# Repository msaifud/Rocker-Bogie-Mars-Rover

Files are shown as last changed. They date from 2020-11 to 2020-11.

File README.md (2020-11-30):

# Rocker-Bogie-Mars-Rover
This project was to construct an autonomous robot to be able to scale the surface of Mars.
Given Mars has an unpredictable and uneven surface the robot would have to maintaining a level body throughout motion in order to keep valuable components within the robot safe. 
Keeping a level body is essential and was done using a differential gear system.
The robot used an Arduino to implement the autonomous behaviour. 
I have attached all the 3D modeled parts, the final assembly as well as renders of the final product (placed into the reports). Moreover, a tenchincal report is also attached explaining the process and solution method. 
Additionally, the landscape was also 3D modeled to replicate an uneven and unpredictable path for the robot. That is also attached.

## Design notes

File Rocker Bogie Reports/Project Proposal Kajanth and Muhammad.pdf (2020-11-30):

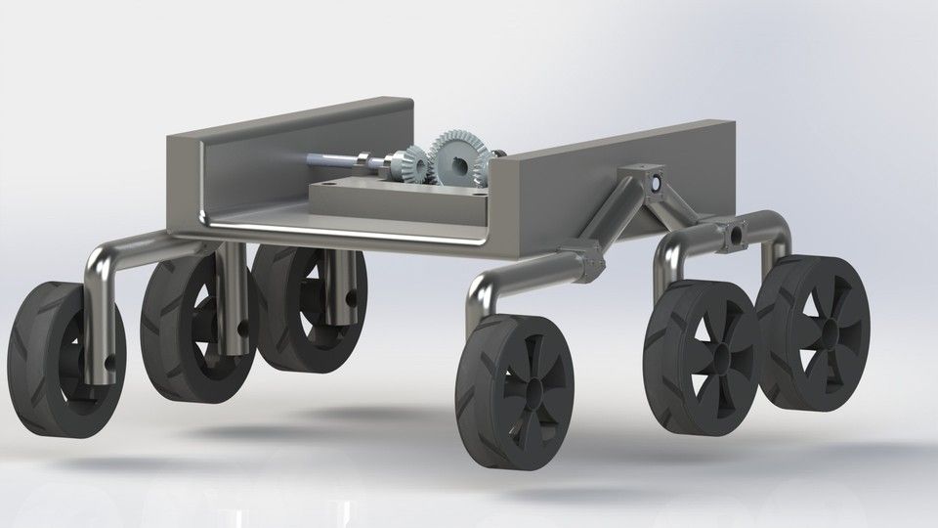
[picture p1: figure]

# Bogie Rocker System Project

09.12.2017
─

## Kajanth Kirupananthan & Muhammad Saifuddin

## Executive Summary

The goal of the following project is to implement the rocker-bogie system into an autonomous robot; which will have the function of keeping a level surface; that will be able to carry a cup from one end of a harsh simulated rocky surface to the other. The following project will involve designing, programming and building an autonomous robot that will be inspired by the bogie-rocker system implemented on the mars rover, said bogie rocker system will be tasked with maintaining a level body even through harsh rocky environments.

## Table of Contents

The Problem and The Fix | 1
Execution Plan | 2
Budgeting | 3
Team Qualifications | 4

## The Problem

Many Space organizations such as Nasa, create explorer devices to go explore the unknowns of our universe and send information back to earth. These devices cost billions to build and produce; these major investments would go to nothing if the explorer robot sustained damaged by the harsh surfaces of the unknown worlds because all the money and time spent on the robot would be lost. To summarize many explorer robots sent to other planets need a system to keep a level surface to protect said robot from sustaining any damage over the course of the exploration mission.

## The Fix

To ensure that all valuable information gets back to earth these robots attempt to implement the rocker-bogie system. The rocker-bogie system uses a series of gears and movable wheels to ensure a level surface that would protect all components from the harsh terrain at all times. Thus, preventing critical blows to the valuable technology and information that is housed in the robot. The following project will attempt to implement the bogie rocker system on a small scale robot as a proof of concept. Said robot will be tasked with proceeding through a simulated rocky path while keeping a level surface at all times to prove the concept of the rocker-bogie system.

## The Execution Plan

### Phase 1: Design Phase (due at the end of September 2017)

- Components that are crucial to the robot must be decided beforehand to ensure the design will account for proper housing or said components.
- Drawings of the exterior body must be drafted to ensure a body that will be able to house both the components of the rocker-bogie system as well as the glass of water itself.
- An inventor cad must be designed to be able to print the frame in such a way that all components may interlock thus, making the assembly of the robot easy. The framework must be designed to be sturdy while also accounting for hidden sections for the wiring to work through.
- Assembly of Robot must show a movable, working wheel and gear system, to ensure that after being built the robot will maintain a level surface.

### Phase 2: Prototyping Phase (1 month)

- The prototype must be made through scraps in the shop at that time to verify a working rocker-bogie system.
- If said prototype does not show the system working successfully, iterations must be made to the cad and the prototype.
- Iterations must be done until Mr.Rattray and both group members are confident with the design of the robot.
- After the design is completed all materials needed must be finalized and ordered.

### Phase 3: Building Phase (until December 2017)

- Building will commence when all materials have arrived
- Parts must be 3d printed beforehand to ensure enough time to build the robot
- All wiring and components must be secured and wiring must be hidden to ensure all components take no damage
- All joints must rotate smoothly

### Phase 4: Programming (second week January)

- Using an Arduino (model to be decided) and all other electrical components on the robot, it must be coded to execute and safely move through a path and keep a stable body to carry a glass of water
- Timings must be made and iterated upon to ensure the robot moves through path correctly
- Code must run perfectly back and forth before the final stage of

### Phase 5: Testing

- The end product must successfully make it through path consistently.
- The end product must also prove its rocker-bogie system is working by keeping a cup of water full even after making it through the path.

## Budgeting

Product | Price | Quantity | Website
Vex motor | $19.99 | 4 | Robotshop
Vex cortex | $324.99 | 1 | Robotshop
Vex battery | $12.99 | 2 | Robotshop
Vex Wiring
3D print material (PLA Filament) | $19.99 | 2 | Robotshop
bearings | To be decided
Differential gear system | To be 3D printed | 1 | N/A
Metals rods | $19.98 | To be decided (diameter of rod is under determination) | Home Depot
Block of wood for cnc | $33.20 | To be decided | Home depot
LED strips | $21.99 | 1 roll | Amazon.ca
High traction vex | $6.99/each | 6 | Vex Robotics

## Team Qualifications: the “Who?”

- Kajanth
- Coding
- Building
- Cading/ CNC
- Designing
- Muhammad
- Cading/CNC
- Building
- Presentation design
- Path design

## Path Followed by Designed Robot

- Description
- The path is designed in this manner for two reasons
■ Because conditions on said planet are extremely unpredictable (one part of the rover can be on a different level than the other)
■ To demonstrate the capabilities of the rover

wheels
Estimated Cost | $550

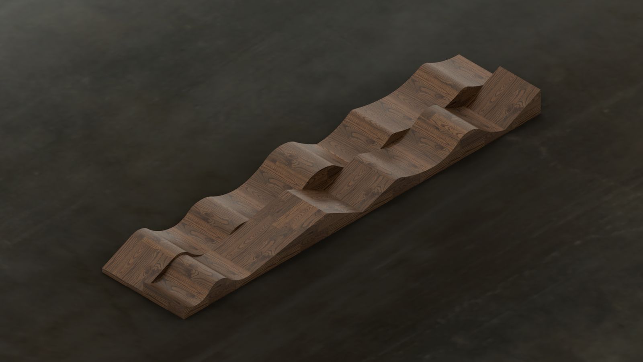
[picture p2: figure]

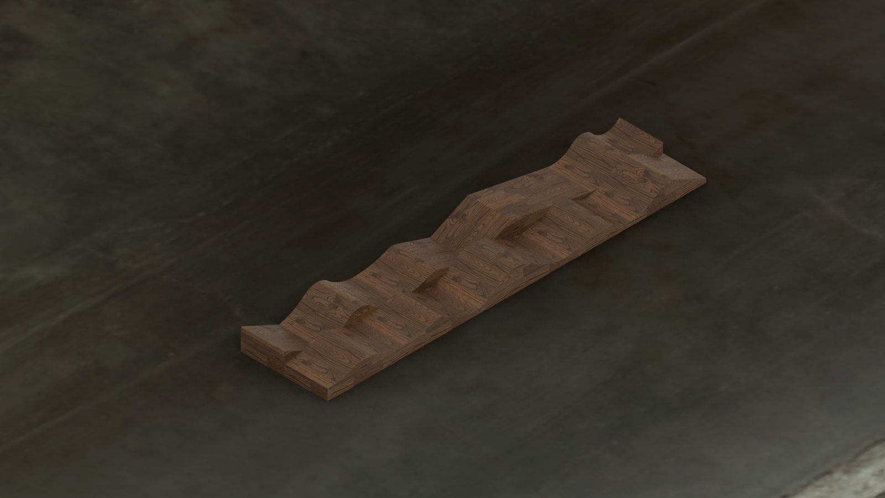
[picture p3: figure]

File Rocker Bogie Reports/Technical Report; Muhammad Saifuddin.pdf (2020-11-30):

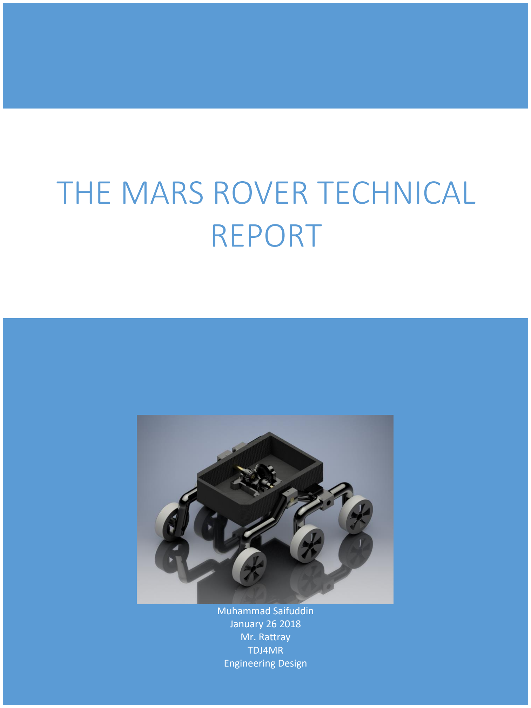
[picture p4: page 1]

Muhammad Saifuddin
January 26 2018
Mr. Rattray
TDJ4MR
Engineering Design

# THE MARS ROVER TECHNICAL REPORT

### The Challenge:

The objective of the Mars Rover assignment was to build a robotic vehicle that would have the capabilities of successfully maneuvering itself through rugged and rigorous surfaces; in addition to this the robot would also have to maintain a level body throughout the course of its movement. Moreover, the robotic vehicle was also given the challenge of recording the gasses in its environment while it was under exploration, this enhanced the simulation of a real mission.

### Rationale:

The proposed challenge has extensive and extremely useful applications. As, in various situations in the real-world, where because of certain circumstances only robotic vehicles can be used oppose to human for exploration; the robot would have to navigate its way through unexpected/harsh terrain while also maintaining a level body. The reason for maintaining a level body is significant to the capabilities of the robot, because at times where the robot is carrying several billion dollar components, if any damage is to be gained then this can compromise the mission in its entirety and defeating the purpose for exploration. Therefore, the robot designed in this specific manner, can be applied to future robots; this ensuring that a misfortunate event of broken components does not occur. Furthermore, the addition of the gas sensors of the robot enhances its capabilities and adds to its effectiveness in the real-world; the data acquired from the robot can be dramatically affect the human race, by detecting gasses that pass as habitable or not, this then allowing humans to create plans for the future, when larger planets are required for the growth of the human race.

### The Brainstorming Stage:

So to complete the challenge at hand, my partner and I first conducted research on past built robots that were specifically designed in a similar manner to the challenge given to us. While conducting research, we came across the Mars Rover; we
then conducted researched on the rocker-bogie. The Mars Rover
featured a rocker-bogie suspension system, the suspension system
worked by focusing on weight balancing; my partner and I saw this as a major flaw because any sudden disorder in the weight
would throw off the balance of the body and would then cause a
damage of the components. The implementation of this suspension

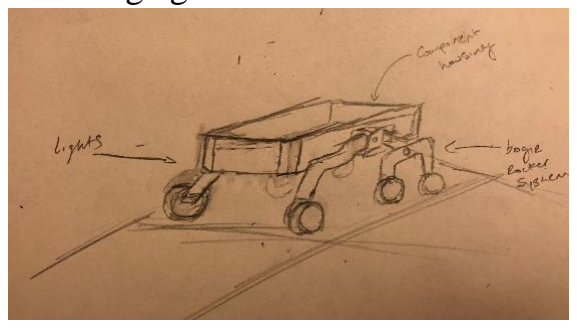
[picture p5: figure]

system was finalized; but the flaw was yet to be fixed. Then through extensive research, we then decided that the addition of a differential gear system would allow for a level body. This is because our design would have shafts that are connected to the gears of the differential system which would ensure a level body when motion occurred. This lead us to the implementation of the differential gear system into our design; it also eliminated the weight balancing factor of the old design and allowed for a level body at all times. After determining a safe a reliable mechanism, we moved on to deciding the technical parts of the robot (types of motors, wiring, etc). While we were in this stage, we decided on certain parts and materials that would ensure a final working robot. For example, in order for our robot’s success we decided to go with 5in wheels and not the regular 4in;

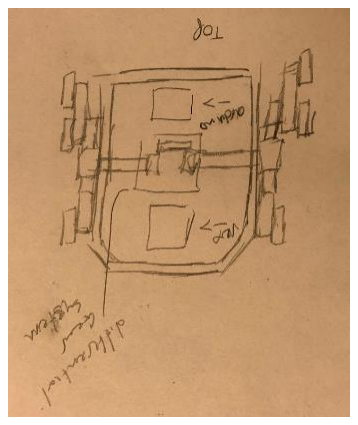
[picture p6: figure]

this is the case because we knew 4 in wheels would not be large enough to go over the hills and bumps presented to us. We then incorporated all the designs into an orthographic sketch as seen above. After we finalized on the design and its technicalities we moved on to creaking a mock up. As you can see on the right, this is the final design; we iterated the initial design as we moved along. From this design we changed certain things, we increased the length of the body to incorporate more space for the components and add to the overall spaciousness to the design. Additionally, we also decided on changing the way the wheels
were placed on the exterior of the robot; we put it on the outside
to remove from any complications from occurring during the

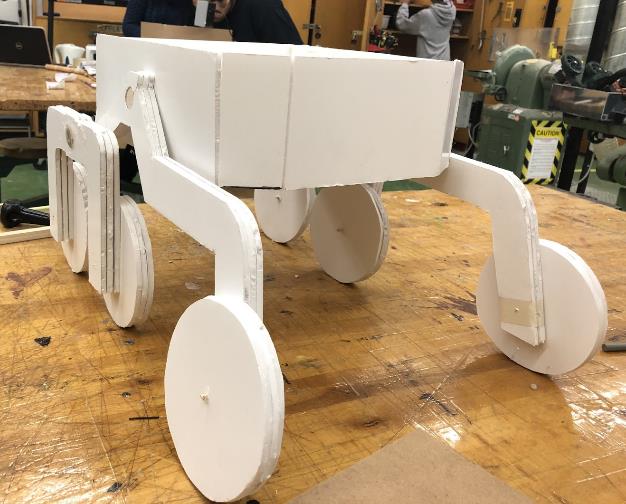
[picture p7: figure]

wiring process. Once all the changes were made, we moved on to creating our robot using AutoDesk Inventor.

### The Electronic Design:

Next, we moved on to creating the robot in its entirety using a computer aided designing software. Using AutoDesk Inventor we achieved this; we first used the software to make individual part, after this was done everything was put into an assembly; we then put the robot together. Then using the same three dimensional software, simulations were done to see whether the robot would work. After this all, the decided parts were 3D printed and the others were made using other decided upon ways. As you can see on right, the 3D design of the robot.

### The Build Process:

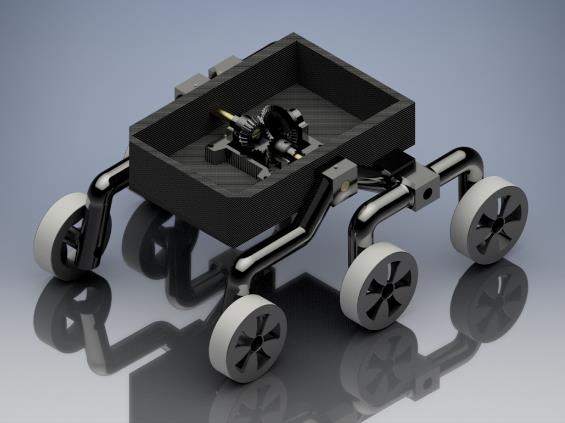
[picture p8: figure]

Once the 3D design of the robot was done, certain parts of the robot were sent to the 3D printers provided to us; here the pieces were printed, certain pieces were reprinted because of printing errors, such as wrapping and sizing errors. The parts of the robot that were printed are, the bogie, the rocker, shafts, the differential gear system and the base plate for holding the differential gear system. Next we were introduced to a new software, which dealt with the CNC machine, this machine was used to create the frame of the body, the frame of the body was made out of wood; likewise, the plating for the frame was then created in a similar manner, where the software was used again and then cut; instead of wood, metal was used for this to help with the aesthetics of the design. Once all of

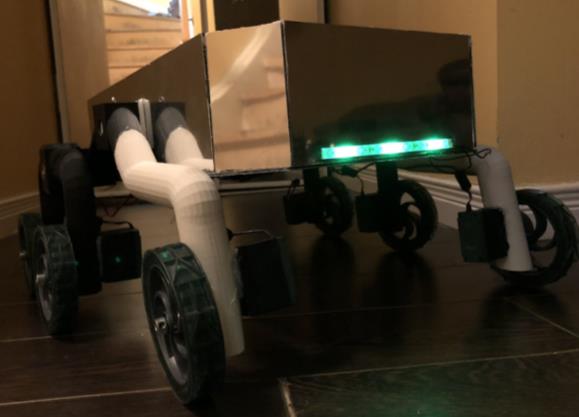
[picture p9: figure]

this was done we gathered everything that was made. Assembling the body of the robot is what was done first, the frame was put together with a strong glue, this was let to dry and then the metal plating was added to all sides of the body, including the interior. Next the base plate was aligned and screwed down to the frame, its components were then added to it (the shaft and the differential gear system). After most of the robot was built, we were came to a decision where we had to choose whether Vex or Arduino motors were going to be used for the robot. After experimenting with both types we finalized out robot to have Vex motors, this is because while experimenting we found that it was much harder to get all the Arduino motors to work in sync, no matter how many times the code was set for the wheels to move in sync, they moved out of sync; we then experimented with Vex motors and found that they always move in sync, allowing for tricky turns. This then lead to the coding part of the assignment, the Vex motors were codded in the controls of a tank. At this stage of building we also codded the gas sensor for the robot, at this moment we realized that we were given the wrong gas sensor because zero parts per million (ppm) was consistently given in all areas where we tested, we the researched the model of the gas sensor, our findings showed us that this specific sensor only gave readings for petrol and natural gases.

### What We Learned:

Throughout the course of designing and building our robot we learned several things. Firstly, the use of the CNC machine and its software; the machine and its software was completely new to both my part and I this meant for a large learning curb, both my partner and I quickly adapted to the new software and were efficient in making what was needed. Secondly, we learned the difference between Vex and Arduino motors; using Vex motors for a more cohesive and more in sync motor, oppose to an uncoordinated and uninform motors. Lastly, the importance of assembling in a mechanical manner; this was discovered after assembling the robot, by the assistance of a mechanical assembly, parts would be able to be replaced and removed at any time.

### Conclusion:

In my opinion I feel like my partner and I accomplished the task at hand, we were able to build a robot that was able to maintain a level body throughout unexpected terrain. However, for future iterations I would improve certain parts drastically to improve its longevity and its efficiency. First I would reprint all 3D parts at hundred percent in fill, this would ensure that when putting the motors through no breaking would occur; next I would add metal shaft and gears to the robot, the shaft would limit or lower the chances of breaking of them occur, also creating metal gears would also for a better mesh and also lower chances of any teeth breaking. In addition to these iterations, I would also make all the joints and fits of the robot to fit in a mechanical manner this would allow for easy access and changing of parts. Lastly, I would switch out the gas sensor, as mentioned before after coding we realized that we were given the wrong gas sensor, replacing this would improve the data collection of the robot. In conclusion, I felt like this assignment was an overall success and hope that this project remains at Chinguacosuy Secondary School for a long time.

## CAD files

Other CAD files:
CAD_Mars_Rover/OldVersions/bogie.0001.ipt
CAD_Mars_Rover/OldVersions/rocker (1).0004.ipt
CAD_Mars_Rover/OldVersions/rocker.0003.ipt
CAD_Mars_Rover/Part1.ipt
CAD_Mars_Rover/Part2.ipt
CAD_Mars_Rover/Part3.ipt
CAD_Mars_Rover/bogie (1).ipt
CAD_Mars_Rover/bogie.ipt
CAD_Mars_Rover/rocker (1).ipt
CAD_Mars_Rover/rocker (1.1).ipt
CAD_Mars_Rover/rocker.ipt
Rover Landscape/landscape for mars rover.ipt
Rover Landscape/mars rover landscape part 2.ipt
